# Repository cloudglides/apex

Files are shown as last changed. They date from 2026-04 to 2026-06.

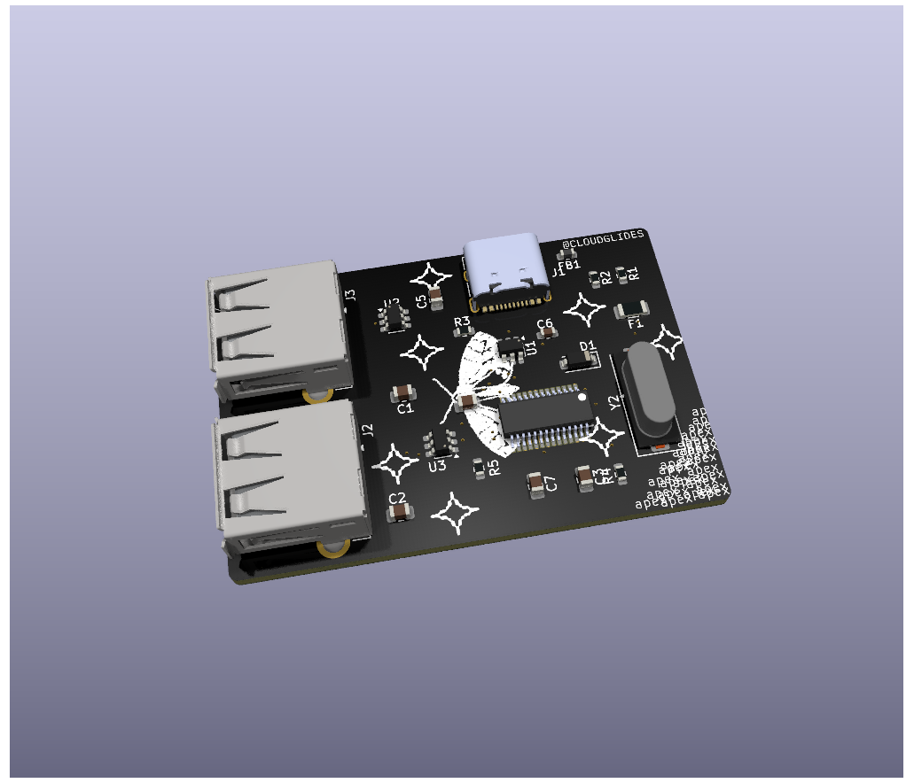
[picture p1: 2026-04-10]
hardware/apex.png

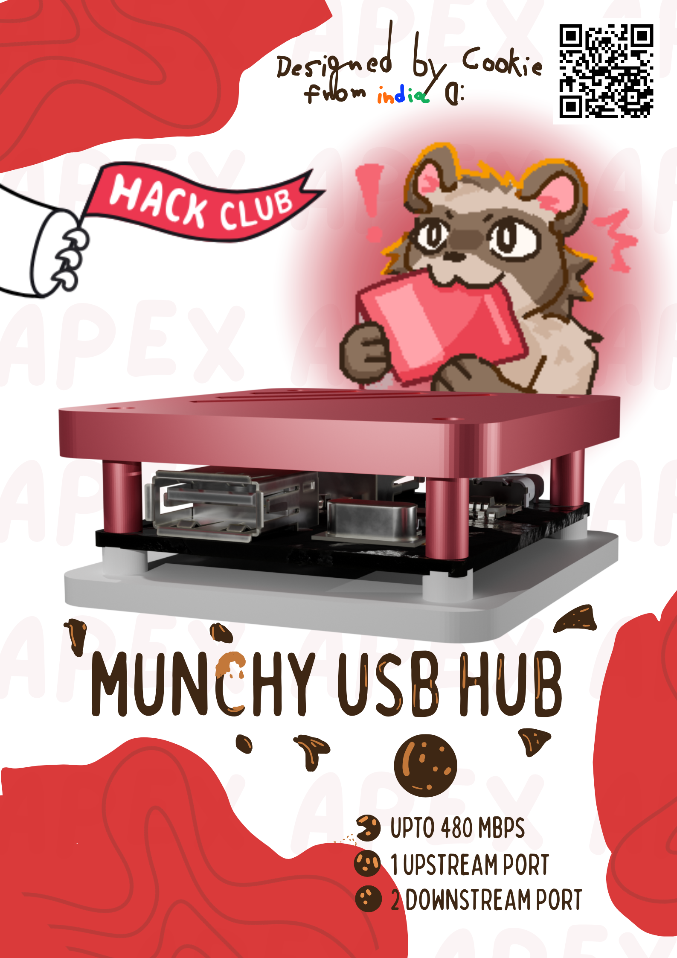
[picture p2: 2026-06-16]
zine/zine.png

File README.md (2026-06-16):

<h1 align="center">
  <br>
  Apex

  <br>
  Apex
  <br>
</h1>
<h4 align="center">
A hub worth looking at.
</h4>
<div align="center">



</div>
<p align="center">
  <a href="#pcb">PCB</a> •
  <a href="#credits">Credits</a> •
  <a href="https://cad.onshape.com/documents/b957cb9eaff1fd55d943d2a3/w/8976d83a889d159a1f08a7bd/e/cf5443223244322f256cbf86">OnShape</a>
</p>

Apex is a custom usb hub PCB built around the Seeed FE1.1S, packing 1 upstream usb-c port, 2 downstream usb-a port.
Built because most usb hub don't let you own what's inside. Apex is made to be reproducible.

## PCB

Designed in KiCad with attention to power management, and equal traces. The board features a 2-layer optimized routing.

## How To build it?

Pretty simple actually, source all the components in BOM and assemble the pcb 
(the project uses smd components so get a pcba if you dont got prior experience)

## Why i made it?

- i wanted to make something
- i had nothing else to make
- i dont got a usb hub either and i really need it

### Schematic


---

### PCB Layers

#### Layer 1


#### Layer 2


---

### Board Views

#### Front


#### Back


### Zine
hgvjvj (2)

## Credits

This project uses:
- [KiCad](https://www.kicad.org/)
- [OnShape](https://cad.onshape.com/) for cad
- [Hack Club Fallout](https://fallout.hackclub.com)

## License

GPL

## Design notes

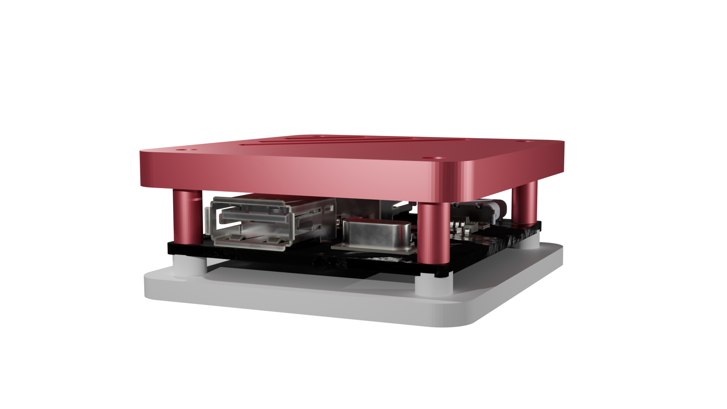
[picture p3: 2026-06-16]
blender/Untitled.png

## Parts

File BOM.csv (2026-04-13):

NAME | UNIT | UNIT PRICE(INR) | PRICE (INR) | PRICE(USD) | SOURCE
10 uF caps | 10 | 13 | 130 | 2 | https://robu.in/product/cc0805kkx5r6bb106-yageo-cap-smd-mlcc-10-%c2%b5f-10-v-0805-2012-metric-10-x5r-cc-series/
100nf caps | 7 | 0.64 | 4.48 | 1 | https://robu.in/product/cc0603jrx7r7bb104-yageo-16v-100nf-x7r-%c2%b15-0603-multilayer-ceramic-capacitors-mlcc-smd-smt-rohs/
4.7uf caps | 10 | 0.56 | 5.6 | 1 | https://robu.in/product/tcc0603x7r475k6r3ct-cctc-smt-ceramic-capacitors-0603-x7r-475k4-7%c2%b5f%c2%b110-rated-voltage6-30v-thickness0-80mm-tape/
diode-sod-123 | 10 | 4.46 | 44.6 | 1 | https://robu.in/product/es1jl-high-diode-1-7v1a-35ns-independent-1a-600v-sod-123fl-fast-recovery-high-efficiency-diodes-rohs/
fuse 1206 | 5 | 21 | 105 | 2 | https://robu.in/product/1206l005-60wr-littelfuse-1206l005-60wr-pptc-resettable-fuse-0-05a-60vdc-1206/
5.1k 0603 resistor | 10 | 0.51 | 5.1 | 1 | https://robu.in/product/ac0603fr-135k1l-yageo-0-1w-thick-film-resistors-%c2%b1100ppm-%e2%84%83-%c2%b11-5-1k%cf%89-0603-chip-resistor-surface-mount-rohs/
fe1.1s | 2 | 100 | 200 | 3 | https://robu.in/product/fe1-1s-bsop28bcn-terminus-tech-ssop-28-150mil-usb-converters-rohs/
12mhz smd crystal | 3 | 10 | 30 | 1 | https://robu.in/product/12mhz-smd-crystal/
220Ω@100mhz ferrite bead | 10 | 0.76 | 7.6 | 1 | https://robu.in/product/upz1608e221-sunlord-%c2%b125-220%cf%89100mhz-0603-ferrite-beads-rohs/
2.7k 0603 resistor | 10 | 0.15 | 1.5 | 1 | https://robu.in/product/ac0603fr-072k7l-yageo-res-thick-film-0603-2-7k-ohm-1-0-1w1-10w-%c2%b1100ppm-c-pad-smd-t-r-automotive-aec-q200/
10k 0603 resistor | 10 | 0.14 | 1.4 | 1 | https://robu.in/product/ac0603jr-0710kl-yageo-res-thick-film-0603-10k-ohm-5-0-1w1-10w-%c2%b1100ppm-c-pad-smd-t-r-automotive-aec-q200/
USBLC6 | 10 | 8 | 80 | 1 | https://robu.in/product/usblc6-2sc6-ms-msksemi-4-5a-15v-150w-6v-5v-sot-23-6-esd-and-surge-protection-tvs-esd-rohs/
usb c | 3 | 38 | 114 | 2 | https://robu.in/product/type-c-31-m-12-hroparts-5a-1-16p-female-type-c-smd-usb-connectors-rohs/
usb a | 2 | 124 | 248 | 3 | https://robu.in/product/uba-4r-d14t-4dlfsn-jst-1a-usb-2-0-1-4p-female-type-a-plugin-usb-connectors-rohs/
pcb | 1 | 1000 | 1000 | 11 | https://robu.in/product/online-pcb-manufacturing-service/
shipping+misc | 1 | 250 | 250 | 3
------------------------ | ------------------------ | ------------------------ | ------------------------ | ------------------------ | ------------------------ | ------------------------ | ------------------------ | ------------------------ | ------------------------
 | 104 |  | 2227.28 | 35

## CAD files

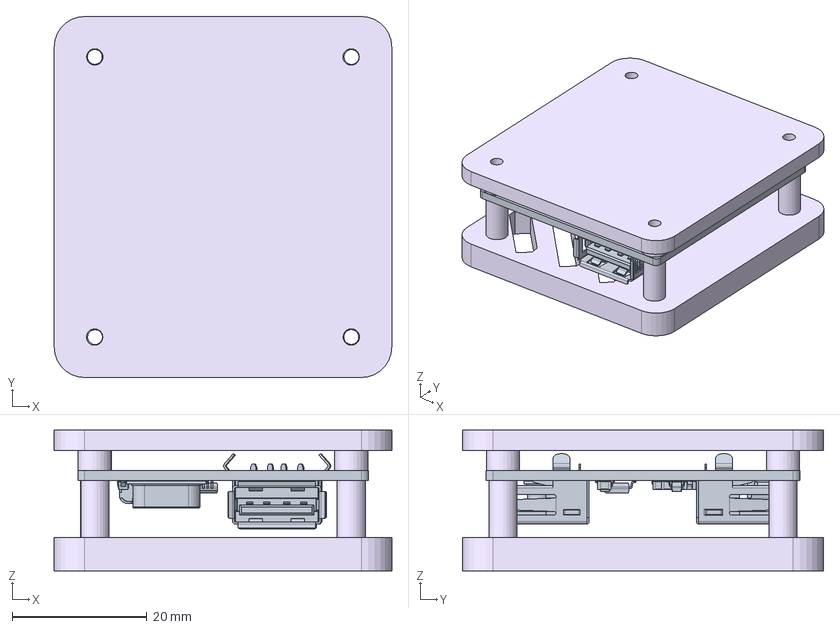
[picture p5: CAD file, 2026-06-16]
onshape/assembly.step
50.1 x 53.6 x 20.9 mm

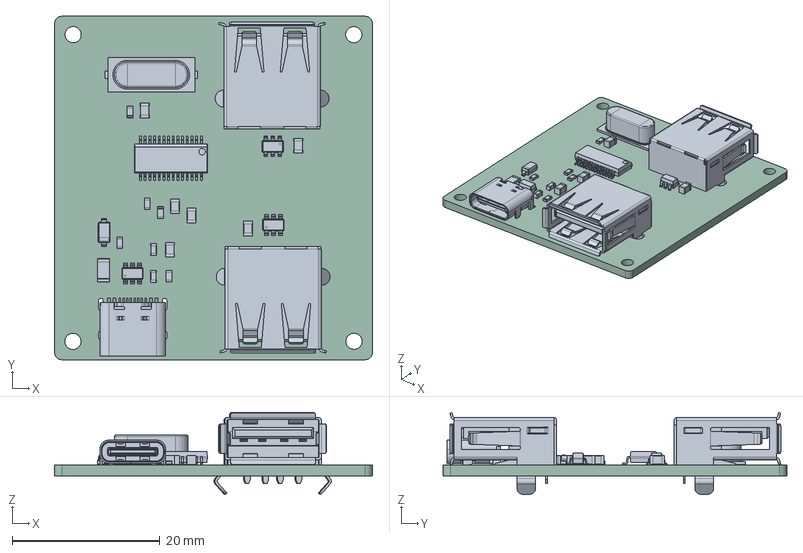
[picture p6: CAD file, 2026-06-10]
hardware/apex.step
43.1 x 46.6 x 11.1 mm
femaleThruHoleUSB x 2
C_0603_1608Metric
R_0603_1608Metric x 5
SOT-23-6 x 3
FE1.1S
C_0805_2012Metric x 6
L_0603_1608Metric
TYPE-C-31-M-12
D_SOD-123
Fuse_1206_3216Metric
Crystal_SMD_HC49-SD
apex_PCB

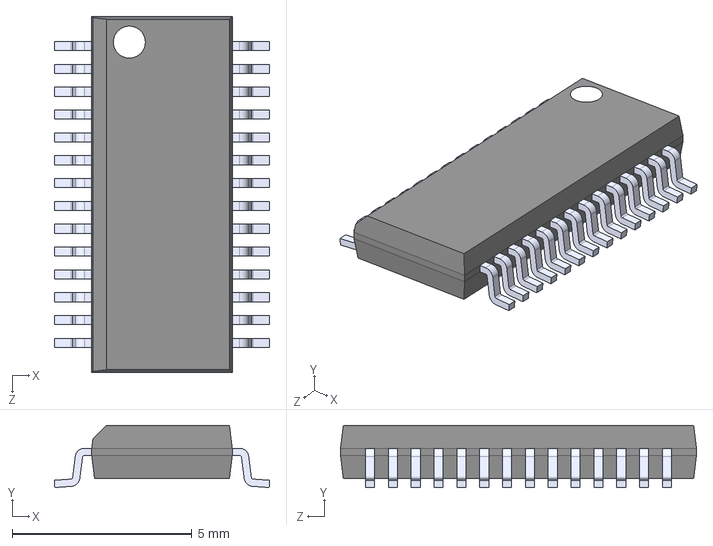
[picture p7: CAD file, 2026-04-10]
hardware/FE1.1S/FE1.1S.step
5.99 x 1.73 x 9.91 mm

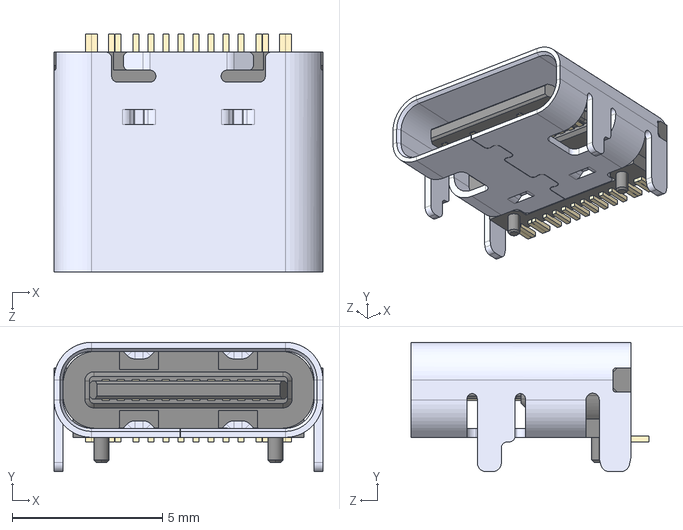
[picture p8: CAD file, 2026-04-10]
hardware/models/TYPE-C-31-M-12--3DModel-STEP-56544.STEP
8.94 x 4.30 x 7.90 mm

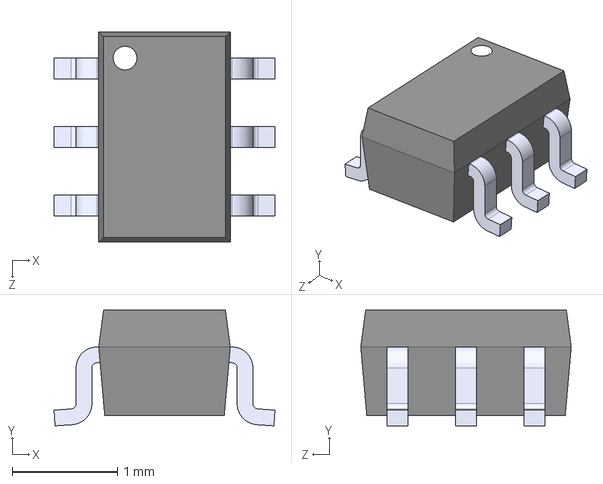
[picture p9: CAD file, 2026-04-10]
hardware/SMF05CT1G/SMF05CT1G.step
2.10 x 1.10 x 2.00 mm

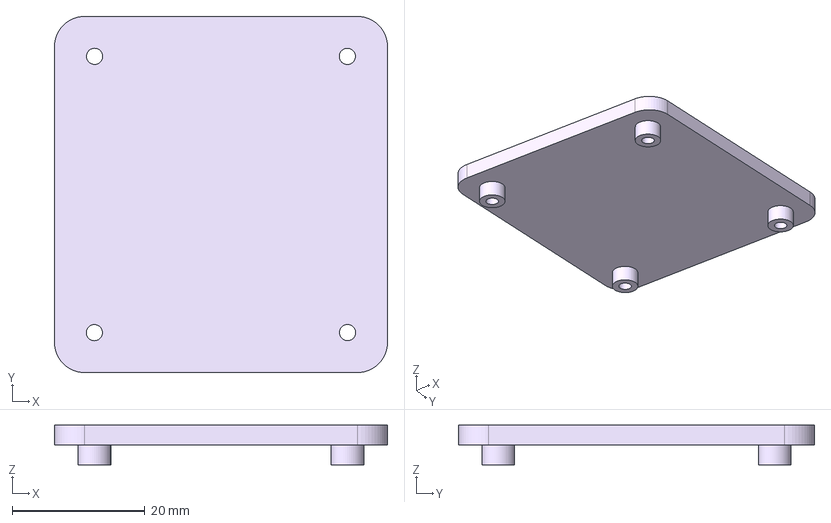
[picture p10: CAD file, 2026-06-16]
onshape/apex.bottom.step
50.1 x 53.6 x 6.00 mm

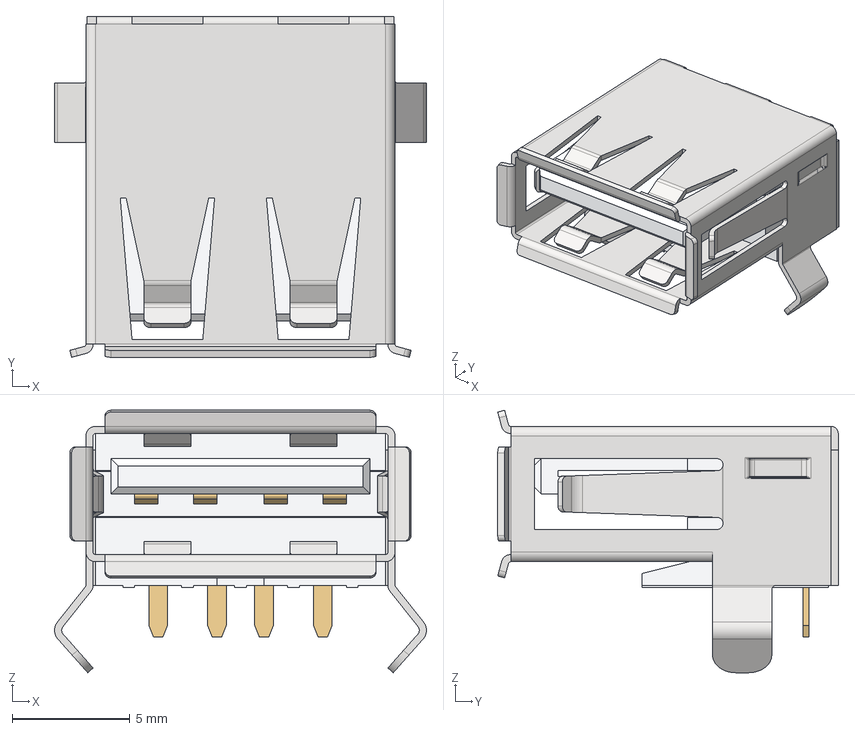
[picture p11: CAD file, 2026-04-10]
hardware/models/femaleThruHoleUSB.stp
15.8 x 14.4 x 11.1 mm

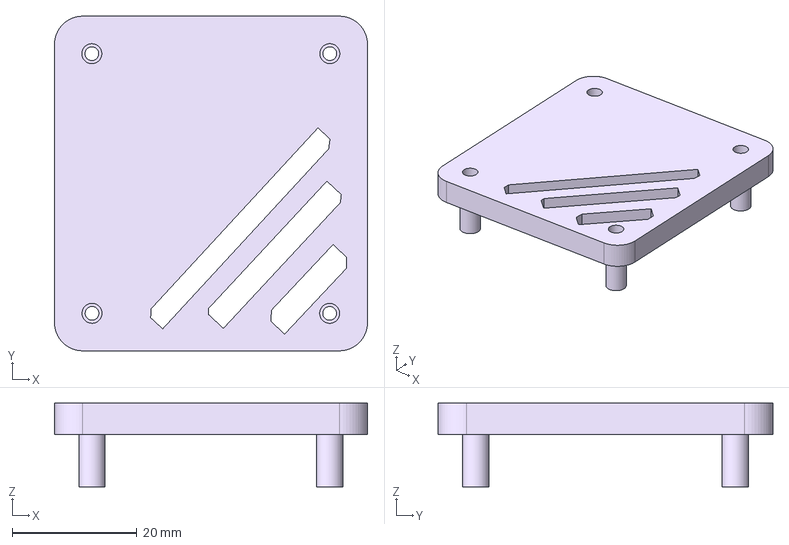
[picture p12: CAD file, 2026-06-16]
onshape/apex.top.step
50.1 x 53.6 x 13.4 mm

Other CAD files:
blender/Untitled.blend
onshape/stl/apex.bottom.stl
onshape/stl/apex.top.stl

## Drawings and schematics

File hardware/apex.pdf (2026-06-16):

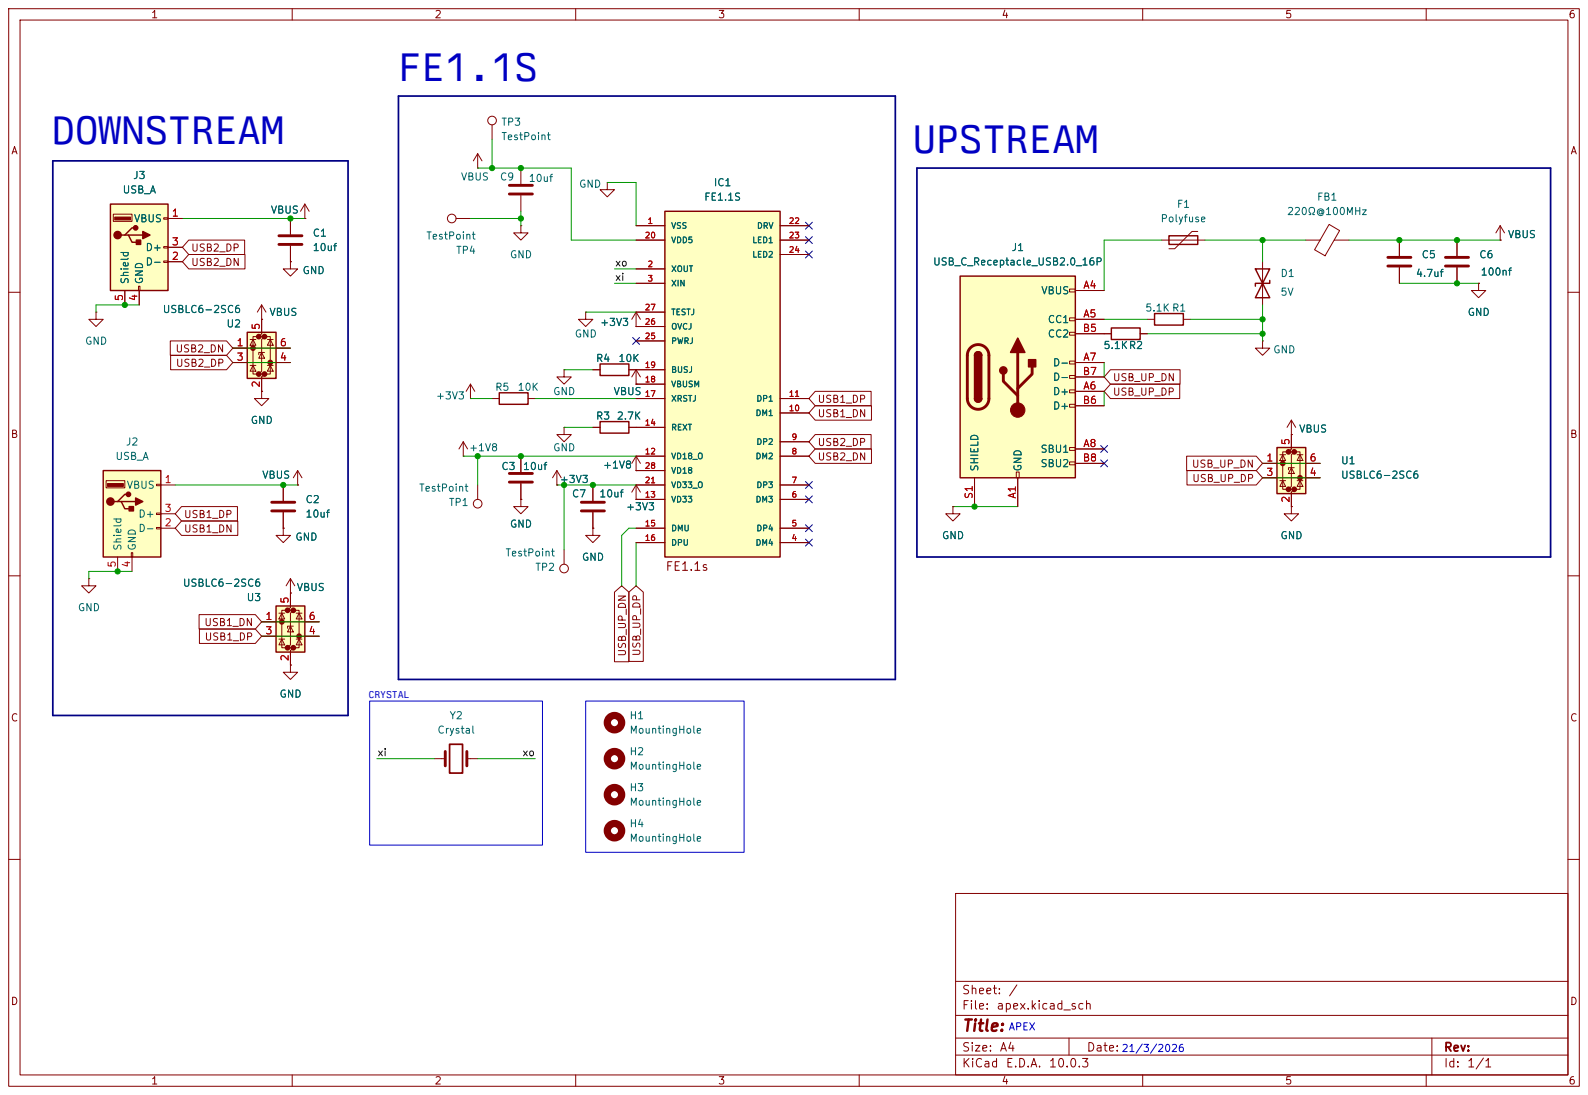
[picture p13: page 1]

VD33 13 REXT 14 DMU 15 DPU 16 VD33 13 REXT 14 DMU 15 DPU 16 VD18 28

SBU2 | B8 SHIELD S1

Size: A4 | 21/3/2026 | Rev:
KiCad E.D.A. 10.0.3 | | Id: 1/1

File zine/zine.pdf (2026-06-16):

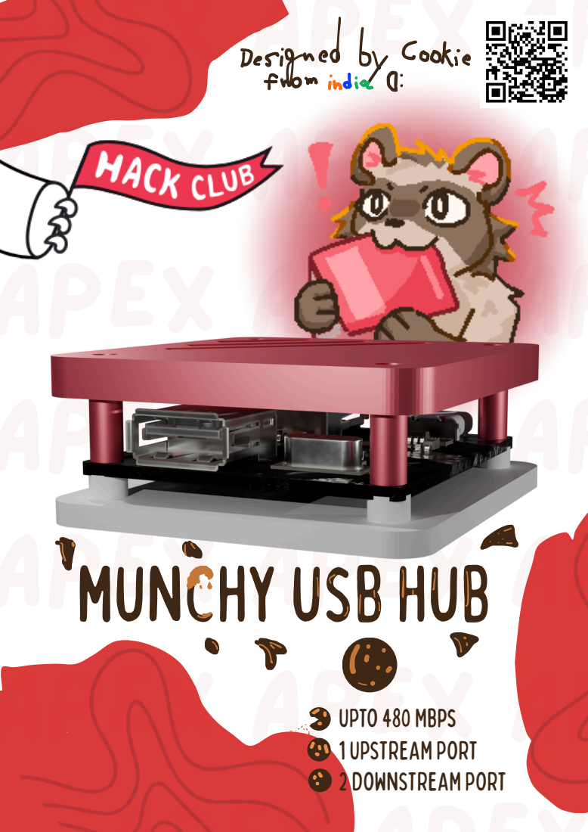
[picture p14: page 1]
UPTO 480 Mbps 1UPSTREAM PORT 2 DOWNSTREAM PORT

APEX (https://magazine.hackclub.com/) APEX AP
APEX APEX AP
munchy usbhub
APEX APEX (https://magazine.hackclub.com/) AP
APEX (https://magazine.hackclub.com/)

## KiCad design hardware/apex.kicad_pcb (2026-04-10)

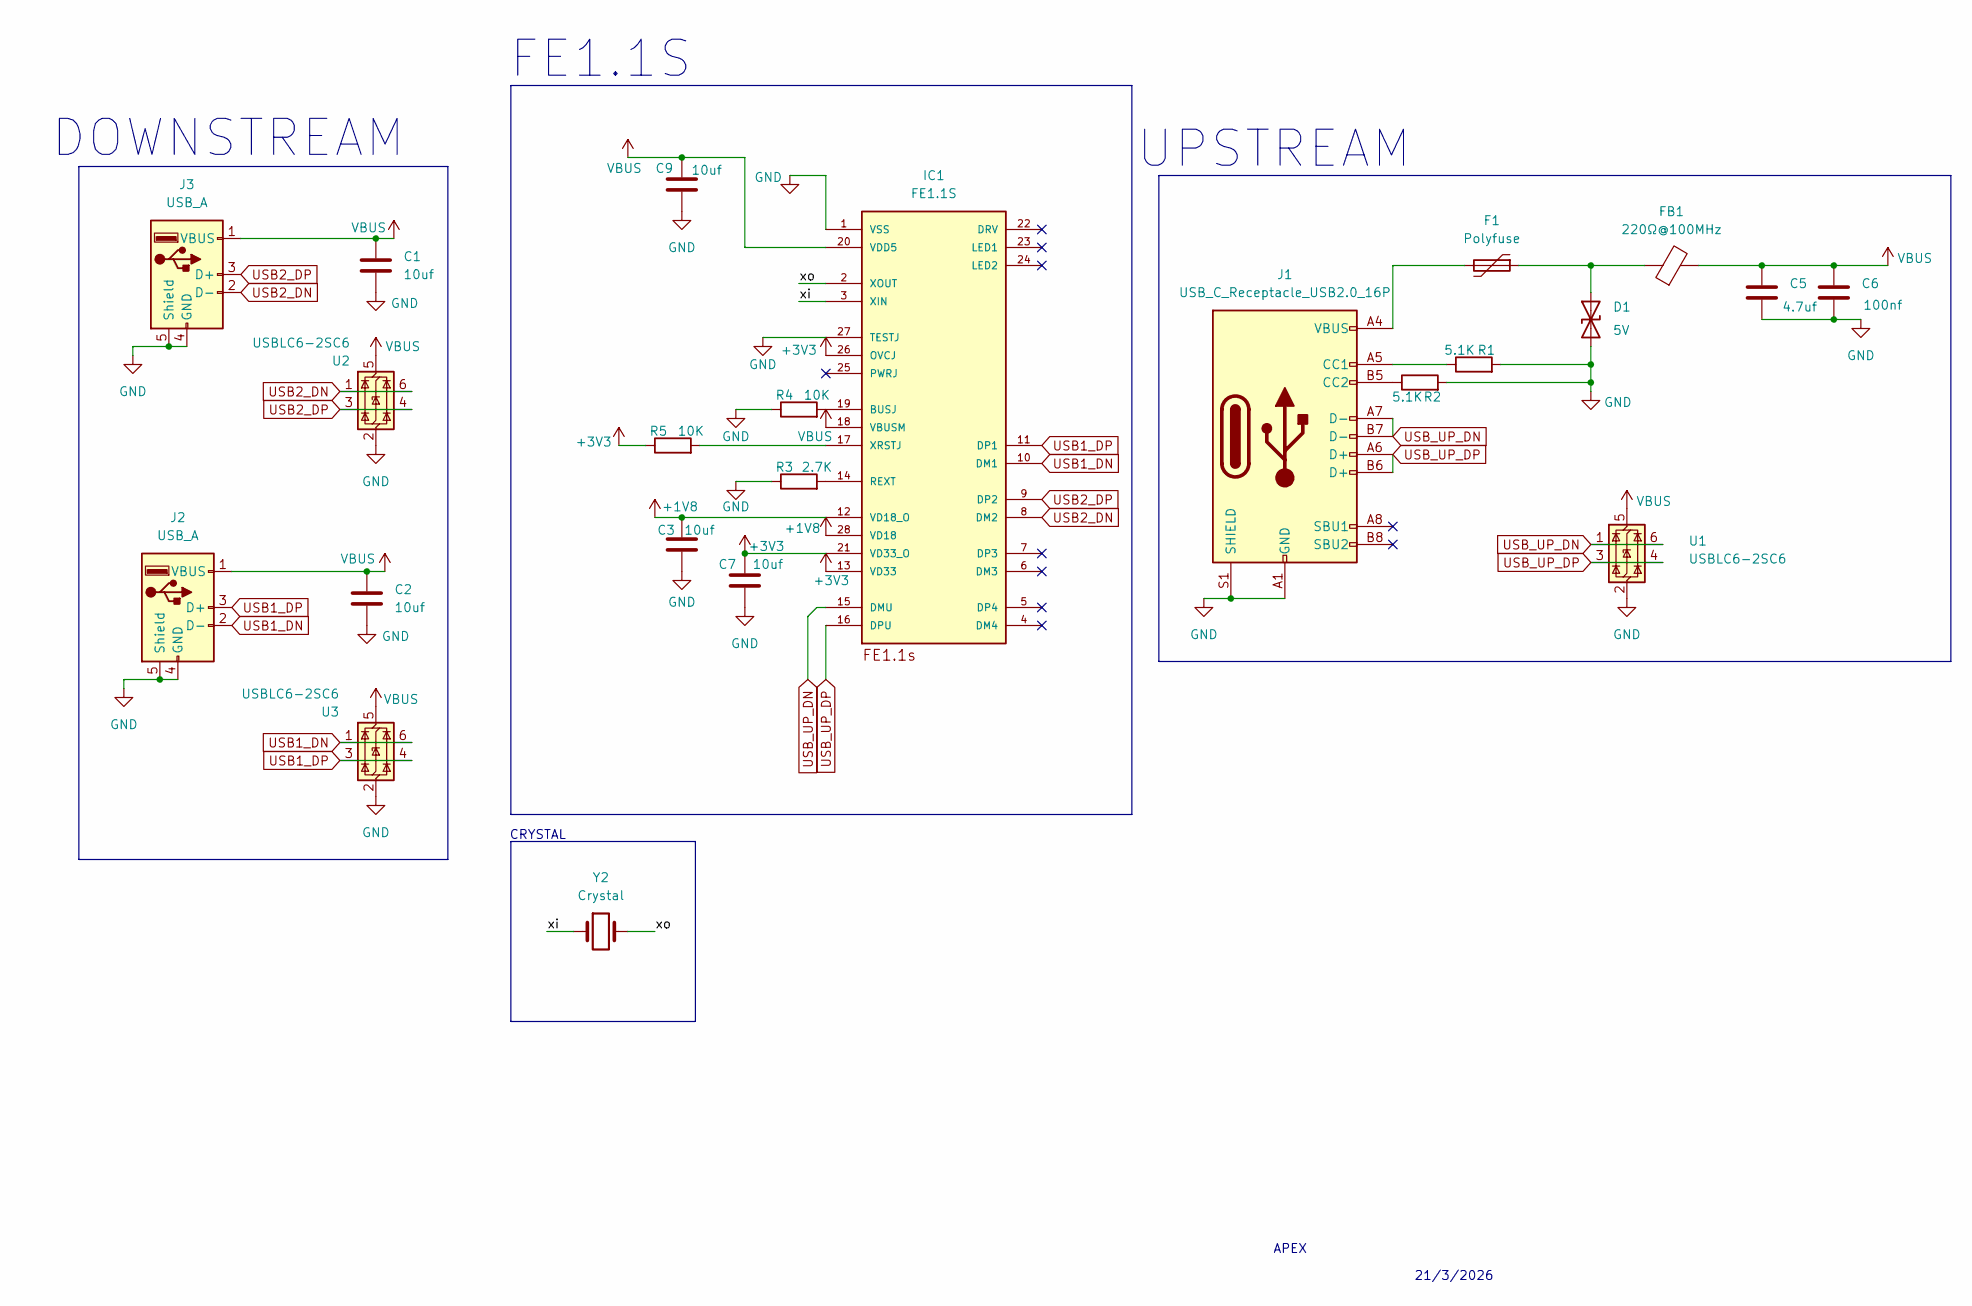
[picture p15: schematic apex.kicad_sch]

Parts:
C1, C2, C3, C7, C9: 10uf; C_0805_2012Metric
C5: 4.7uf; C_0805_2012Metric
C6: 100nf; C_0603_1608Metric
D1: 5V; D_SOD-123; LCSC Part C82044
F1: Polyfuse; Fuse_1206_3216Metric
FB1: 220Ω@100MHz; L_0603_1608Metric
IC1: FE1.1S; FE1.1S_SSOP-28
J1: USB_C_Receptacle_USB2.0_16P; USB_C_Receptacle_XKB_U262-16XN-4BVC11
J2, J3: USB_A; USB_A_Connfly_DS1095
R1, R2: 5.1K; R_0603_1608Metric
R3: 2.7K; R_0603_1608Metric
R4, R5: 10K; R_0603_1608Metric
U1, U2, U3: USBLC6-2SC6; SOT-23-6
Y2: Crystal; Crystal_SMD_HC49-SD

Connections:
+1V8: C3.1, IC1.12 (VD18_O), IC1.28 (VD18)
+3V3: C7.1, IC1.13 (VD33), IC1.21 (VD33_O), IC1.26 (OVCJ), R5.1
/xi: IC1.3 (XIN), Y2.1
/xo: IC1.2 (XOUT), Y2.2
GND: C1.2, C2.2, C3.2, C5.2, C6.2, C7.2, C9.2, D1.2 (A2), IC1.1 (VSS), IC1.27 (TESTJ), J1.A1 (GND), J1.A12 (GND), J1.B1 (GND), J1.B12 (GND), J1.S1 (SHIELD), J2.4 (GND), J2.5 (Shield), J3.4 (GND), J3.5 (Shield), R1.2, R2.2, R3.1, R4.1, U1.2 (GND), U2.2 (GND), U3.2 (GND)
unnamed: D1.1 (A1), F1.1, FB1.1
unnamed: F1.2, J1.A4 (VBUS), J1.A9 (VBUS), J1.B4 (VBUS), J1.B9 (VBUS)
unnamed: IC1.19 (BUSJ), R4.2
unnamed: IC1.14 (REXT), R3.2
unnamed: IC1.17 (XRSTJ), R5.2
unnamed: J1.A5 (CC1), R1.1
unnamed: J1.B5 (CC2), R2.1
USB1_DN: IC1.10 (DM1), J2.2 (D-), U3.1 (I/O1), U3.6 (I/O1)
USB1_DP: IC1.11 (DP1), J2.3 (D+), U3.3 (I/O2), U3.4 (I/O2)
USB2_DN: IC1.8 (DM2), J3.2 (D-), U2.1 (I/O1), U2.6 (I/O1)
USB2_DP: IC1.9 (DP2), J3.3 (D+), U2.3 (I/O2), U2.4 (I/O2)
USB_UP_DN: IC1.15 (DMU), J1.A7 (D-), J1.B7 (D-), U1.1 (I/O1), U1.6 (I/O1)
USB_UP_DP: IC1.16 (DPU), J1.A6 (D+), J1.B6 (D+), U1.3 (I/O2), U1.4 (I/O2)
VBUS: C1.1, C2.1, C5.1, C6.1, C9.1, FB1.2, IC1.18 (VBUSM), IC1.20 (VDD5), J2.1 (VBUS), J3.1 (VBUS), U1.5 (VBUS), U2.5 (VBUS), U3.5 (VBUS)

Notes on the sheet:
21/3/2026
CRYSTAL
FE1.1S
DOWNSTREAM
UPSTREAM
APEX

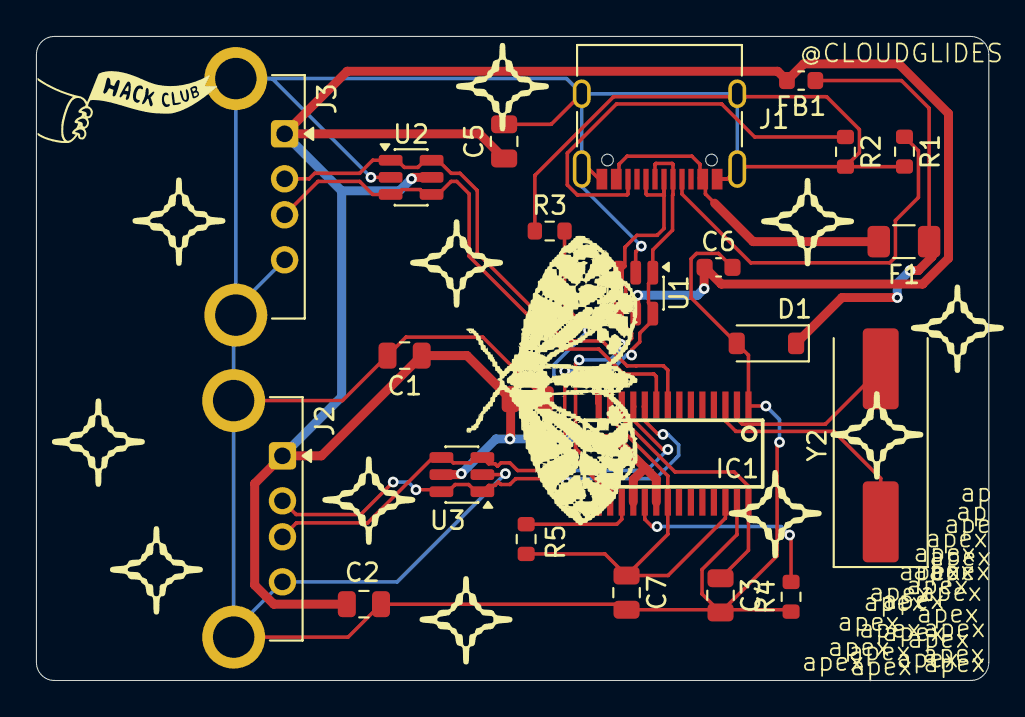
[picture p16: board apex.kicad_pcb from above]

Board: 2 copper layers, 52.9 x 35.8 mm, 23 parts (0 on the bottom side), 19 nets.

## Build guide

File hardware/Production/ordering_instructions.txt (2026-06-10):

Ordering Instructions:
Panel dimensions: 100.47 x 60.33 mm.
Solder Mask: Red (Default)
Silkscreen: White (Default)
Layers: 2
Finish: HASL Lead-free (Default)
Thickness: 1.6mm (Default)
Copper weight: 1oz (Default)
Minimum track width: 0.20mm (7.87mil)
Minimum via drill: 0.30mm (11.81mil)

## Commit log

2026-04-10 inital commit
    [FE1.1S.step, SMF05CT1G.step, TYPE-C-31-M-12--3DModel-STEP-56544.STEP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]
2026-04-13 add: BOM
    [BOM.csv]
2026-06-10 revise: apex_2
    [Untitled.blend, apex.bottom.stl, apex.case.bottom.step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]
2026-06-16 update: cad formats
    [apex.bottom.step, apex.bottom.stl, apex.top.step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]
2026-06-16 chore:update zine
    [Untitled.blend]
2026-06-16 Add build instructions and motivation section to README
    Added a section on how to build the PCB and reasons for its creation.
